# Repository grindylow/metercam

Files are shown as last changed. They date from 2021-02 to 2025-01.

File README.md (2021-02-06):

# MeterCam

A WiFi "webcam" to monitor gas/water/electricity meters, or anything else that
needs regular (daily/weekly/monthly) inspection. When set to weekly intervals,
MeterCam will run on one set of AAA batteries for many years.

## Introduction

The MeterCam combines a standard ESP32-CAM module [1] (which works great, but
consumes a lot of power, even when sleeping) with custom hardware that only
powers up the camera module when it wants to take a picture, for example once
a day/week.

This custom hardware utilises a very energy-efficient "high-side power switch"
and a low-power microcontroller - keeping the power consumption during sleep
periods below 1 µW and resulting in battery lifetimes of many years.

## Features

- [ ] Configurable WiFi SSID/password
- [ ] Extended configuration options
- [ ] Configuration change via MQTT
- [ ] Image output via MQTT
- [ ] image acquisition on boot
- [ ] enable/disable "flash" LED
- [ ] Streaming video over HTTP (for setup)
- [ ] request shutdown

## Setup Instructions

The configuration web interface is based around XYZ's WifiManager[...].

A virgin MeterCam will enter configuration mode when first powered up.

Connect to the MeterCam WiFi Access Point (SSID "METERCAM", password:
"metercam") and configure all parameters as desired.

From now on, MeterCam will wake up at the configured intervals (see
[below](#operation)).

@todo you can force a configured MeterCam to go back into configuration mode
by setting jumper JPx. MeterCam will also fall back to configuration mode if
it hasn't been able to connect to the configured WiFi network five times in a
row (this is a feature of WifiManager).

## Operation

No maintenance is required during regular operation. MeterCam will

 1. wake up every interval
 2. connect to the configured WiFi
 3. take a picture
 4. transmit this picture via the configured means (MQTT, E-Mail, FTP, etc.)
 5. go back to sleep

@todo If MQTT is enabled, the MeterCam will subscribe to the configured "inbox" topic
and interpret incoming configuration requests.

## Detailed Description of MeterCam Components

### MeterCam Printed Circuit Board (PCB)

The MeterCam PCB contains a Microchip PIC16 microcontroller. It communicates
with the ESP32-CAM module via a bidirectional serial link. This link allows the
ESP32-CAM to request power-off and specific sleep durations.

The microcontroller also controls a "high-side power switch" used to cut power
to the ESP32-CAM module - thereby preventing the ESP32-CAM from consuming any
power during periods of inactivity.

### MeterCam µC Firmware

The software running on the MeterCam's microcontroller performs the following
tasks:

 - [ ] On initial bootup, switch *on* ESP32-CAM module, then wait for shutdown
   command .
 - [ ] Switch *off* ESP32-CAM module after 20 seconds, even if no
   (shutdown) command was received. Use a default sleep time of approximately 1 day in this case, if now other time has previously been configured.
 - [ ] Switch *off* ESP32-CAM when requested (via serial connection), and sleep
   for requested duration, consuming as little power as possible.
 - [ ] Switch *on* ESP32-CAM when requested sleep duration has passed.

ESP32-Firmware and µC-Firmware communicate via serial ports. The µC acts as the
slave and will respond to the following commands when transmitted by the ESP32:

| Command | Reply | Explanation |
|---|---|---|
| 'E' | 'e' | Echo request/reply - for testing the connection |
| 'A' <HI> <LO> | 'a' <HI> <LO> | Set new sleep time in 'intervals'. |
| 'S' | 's' | Switch off power to ESP32 'now' and sleep for configured sleep duration |

### MeterCam ESP32-CAM Firmware

Compile using Arduino Studio with ESP extensions and the following libraries:
 - ESP32-CAM
 - [WifiManager](https://github.com/tzapu/WiFiManager)
 - -[DoubleResetDetect](https://github.com/jenscski/DoubleResetDetect)-
 - [EspMQTTClient](https://github.com/plapointe6/EspMQTTClient), which requires...
   - [MQTT PubSubClient](https://github.com/knolleary/pubsubclient)
 - [ArduinoJSON](https://arduinojson.org/)

[1] ESP32-CAM module: ...

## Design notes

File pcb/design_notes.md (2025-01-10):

# Power Supply

The ESP32CAM-Module is designed to operate from 5 V DC power.

According to the schematic, e.g. in [1], this is internally converted to
3.3 V with an AMS1117 regulator. At the expense of additional heat
dissipation, this will easily work with > 5 V.

In an alternative design, we could switch 4.5 V (from 3 AAA batteries) and
convert these to 3.3 V ourselves with a very low drop regulator.

We choose a power supply of 4 x AAA batteries. These will give a voltage of
1.6 V x 4 = 6.4 V (see, e.g., [2]).

The ESP32COM datasheet gives maximum power consumption of 310 mA  @ 5 V.

The AMS1117 guarantees a maximum dropout voltage of 1.3 V. For 3.3 V output,
we can safely operate down to 3.3 V + 1.3 V = 4.6 V.

4.6 V translates into a single battery voltage of 4.6 V / 4 = 1.15 V.

According to [2], when discharged at 250 mA, the battery voltage will drop to
1.15 V in about 1.5 hours. This roughly marks the end of usable live time.

## MCU Power Supply

The Microchip PIC16F15213 is rated from 1.8 V to 5.5 V. However, the
"absolute maximum ratings" list a permissible operating voltage of up to
6.5 V, which is higher than our maximum battery voltage of 6.4 V.

Hence, no additional voltage dropping diodes are needed.

Serial communication to the ESP32 should also work work both at "full" and
"empty" battery voltage levels (tbc).

## Power Switch Power Supply

The SIP32510 is rated for a maximum operating voltage of 6.0 V.

We operate outside the specification by 0.4 V during off periods, which should
not be a problem.

EN input high voltage must be >= 1.8 V (for V_IN = 5.0 V) which will be the
case even at the end of the battery life time.

An alternative design could employ a simple MOSFET instead of a power switch.

The MCU's charge pump feature may be beneficial in this case?

[1]: https://github.com/SeeedDocument/forum_doc/blob/master/reg/ESP32_CAM_V1.6.pdf

[2]: Duracell AAA: https://docs.rs-online.com/3eb6/A700000006538580.pdf

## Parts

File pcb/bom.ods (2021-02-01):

Bill of Materials
MeterCam
r1
 | Mouser-Nr. | Herst.- Nr. | Hersteller | Kunden-Teilenr | Beschreibung | Stückzahl | Preis (EUR) | Gesamtpreis: (EUR)
ICs
1 | 579-PIC16F15213-I/SN | PIC16F15213-I/SN | Microchip |  | 8-Bit Mikrocontroller - MCU | 3 | 0,356 € | 1,07 €
3 | 78-SIP32510DT-T1-GE3 | SIP32510DT-T1-GE3 | Vishay |  | Leistungsschalter IC - Leistungsverteiler 1.1V to 5.5V Slew Rt 3A Cntrld Load Swtch | 3 | 0,322 € | 0,97 €
Capacitors
4 | 80-C0805C104K4R | C0805C104K4RACTU | KEMET |  | Kondensator aus mehreren Keramikschichten MLCC - SMD/SMT 16V 1uF X7R 0805 10% | 9 | 0,085 € | 0,77 €
6 | 80-C0805C103K4R | C0805C103K4RACTU | KEMET |  | Kondensator aus mehreren Keramikschichten MLCC - SMD/SMT 16V 0.01uF X7R 0805 10% | 3 | 0,119 € | 0,36 €
LEDs
7 | 604-AP2012ID | AP2012ID | Kingbright |  | Standard-LEDs - SMD Red 625nm 5mcd 120 Deg | 6 | 0,195 € | 1,17 €
Resistors
8 | 71-CRCW080510K0FKEAC | CRCW080510K0FKEAC | Vishay |  | Dickfilmwiderstände - SMD 1/8Watt 10Kohms 1% Commercial Use | 10 | 0,05 € | 0,50 €
9 | 71-CRCW080520K0FKEAC | CRCW080520K0FKEAC | Vishay |  | Dickfilmwiderstände - SMD 1/8Watt 20Kohms 1% Commercial Use | 6 | 0,085 € | 0,51 €
10 | 71-CRCW0805470RFKEAC | CRCW0805470RFKEAC | Vishay |  | Dickfilmwiderstände - SMD 1/8Watt 470ohms 1% Commercial Use | 3 | 0,085 € | 0,26 €
11 | 71-CRCW08051K00FKEAC | CRCW08051K00FKEAC | Vishay |  | Dickfilmwiderstände - SMD 1/8Watt 1Kohms 1% Commercial Use | 6 | 0,085 € | 0,51 €
12 | 71-CRCW0805100RFKEAC | CRCW0805100RFKEAC | Vishay |  | Dickfilmwiderstände - SMD 1/8Watt 100ohms 1% Commercial Use | 3 | 0,085 € | 0,26 €
Connectors
13 | 200-SNT100BKT | SNT-100-BK-T | Samtec |  | Sockel & Kabelgehäuse .100" Shunt | 9 | 0,169 € | 1,52 €
14 | 538-22-28-4360 | 22-28-4360 | Molex |  | Sockel & Kabelgehäuse 36P 1 ROW VERT HDR | 2 | 0,686 € | 1,37 €
2 | 200-SSW10801TS | SSW-108-01-T-S | Samtec |  | Platine-zu-Platine & Mezzanine-Steckverbinder .100" Tiger Buy Socket Strip | 6 | 0,695 € | 4,17 €
Other
5 | 12BH431/C-GR | 12BH431/C-GR | Eagle Plastic Devices |  | Batteriegehäuse 3 AAA W/COVER | 3 | 1,81 € | 5,43 €
15 | 5174-11161 | FP301-1/16-48"-Black-Bulk | 3M |  | Wärmeschrumpfschläuche & -hülsen 2:1 Thin Wall 1/16, 48" Black | 1 | 1,49 € | 1,49 €

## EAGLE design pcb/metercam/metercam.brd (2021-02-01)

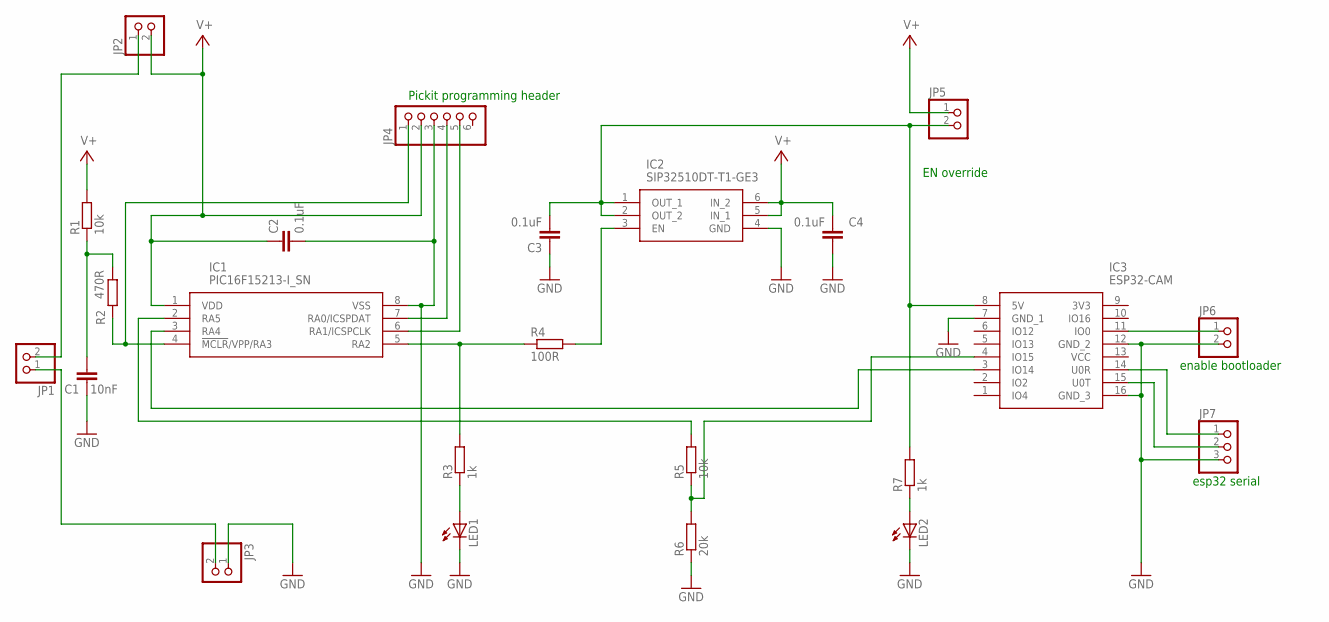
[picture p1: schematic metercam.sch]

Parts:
C1: 10nF; C0805
C2, C3, C4: 0.1uF; C0805
IC1: PIC16F15213-I_SN; SOIC127P600X175-8N
IC2: SIP32510DT-T1-GE3; SOT95P284X110-6N
IC3: ESP32-CAM; ESP32CAM
JP1, JP2, JP3, JP5, JP6: PINHD-1X2; 1X02
JP4: PINHD-1X6; 1X06
JP7: PINHD-1X3; 1X03
LED1, LED2: LEDSML0805; SML0805
R1, R5: 10k; R0805
R2: 470R; R0805
R3, R7: 1k; R0805
R4: 100R; R0805
R6: 20k; R0805

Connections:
GND: C1.1, C2.2, C3.1, C4.1, IC1.8 (VSS), IC2.4 (GND), IC3.7 (GND_1), IC3.12 (GND_2), IC3.16 (GND_3), JP3.1, JP4.3, JP6.2, JP7.3, LED1.C, LED2.C, R6.1
unnamed: IC1.4 (!MCLR!/VPP/RA3), JP4.1, R2.1
unnamed: IC3.14 (U0R), JP7.1
unnamed: JP1.2, JP2.1
unnamed: IC1.7 (RA0/ICSPDAT), JP4.4
unnamed: IC1.6 (RA1/ICSPCLK), JP4.5
unnamed: IC3.11 (IO0), JP6.1
unnamed: JP1.1, JP3.2
unnamed: IC3.15 (U0T), JP7.2
unnamed: IC1.5 (RA2), R3.2, R4.1
unnamed: IC2.3 (EN), R4.2
unnamed: C3.2, IC2.1 (OUT_1), IC2.2 (OUT_2), IC3.8 (5V), JP5.2, R7.2
unnamed: LED2.A, R7.1
unnamed: LED1.A, R3.1
unnamed: IC1.3 (RA4), IC3.3 (IO14)
unnamed: IC1.2 (RA5), R5.2
unnamed: IC3.4 (IO15), R5.1, R6.2
unnamed: C1.2, R1.1, R2.2
V+: C2.1, C4.2, IC1.1 (VDD), IC2.5 (IN_1), IC2.6 (IN_2), JP2.2, JP4.2, JP5.1, R1.2

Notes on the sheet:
Pickit programming header
enable bootloader
esp32 serial
EN override

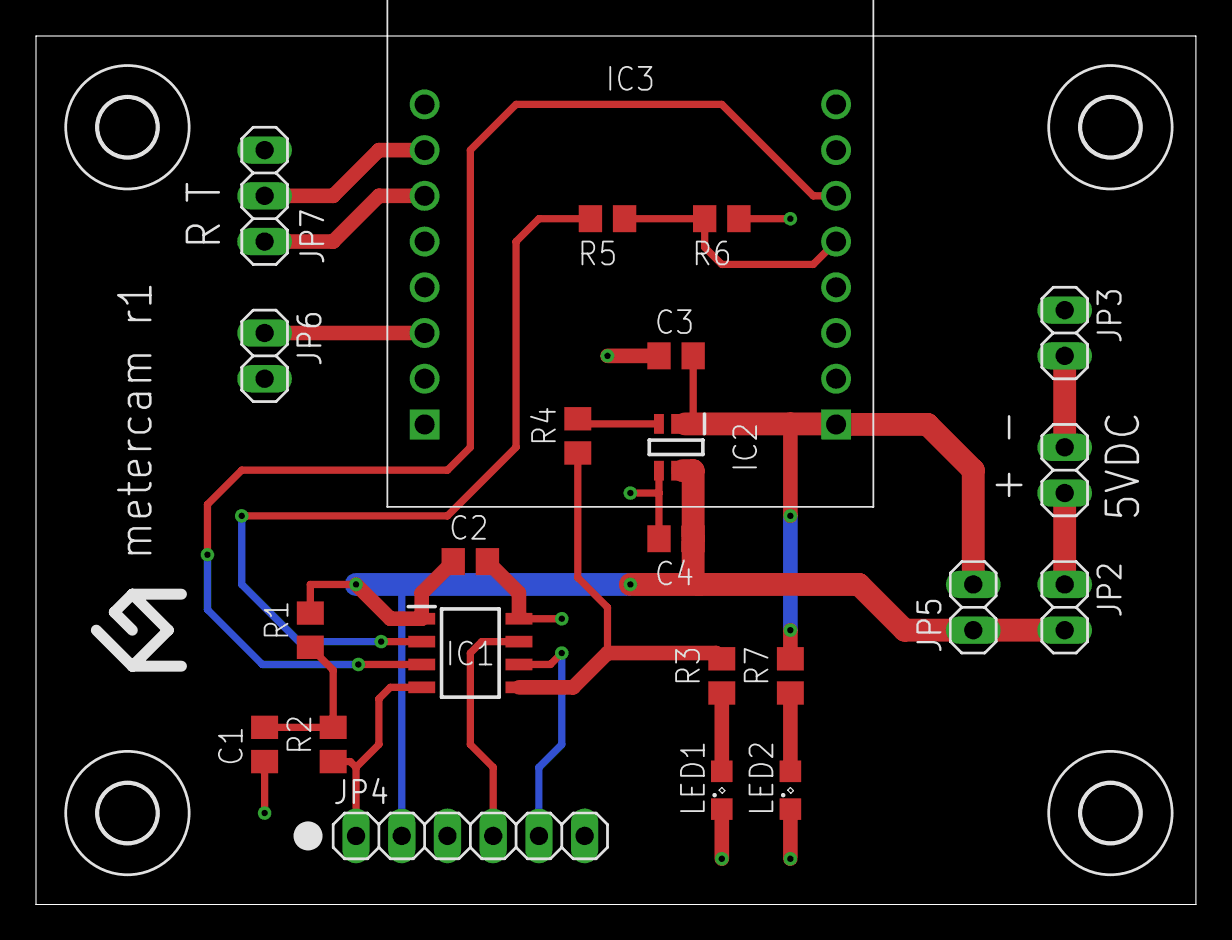
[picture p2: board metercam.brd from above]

Board: 2 copper layers, 64.4 x 48.2 mm, 27 parts (0 on the bottom side), 19 nets.

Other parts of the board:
U$1, U$2, U$3, U$4: 3,2

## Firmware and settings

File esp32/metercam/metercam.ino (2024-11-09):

/* MeterCam by Martin Grill
 *  ......
 * License: ...
 */

/* https://github.com/khoih-prog/ESP_DoubleResetDetector/  -  EEPROM doesn't work, LITTLEFS crashes! */
//#include <ESP_DoubleResetDetector.h>  

/* https://github.com/tzapu/WiFiManager */
#include <WiFiManager.h>  

///* https://github.com/plapointe6/EspMQTTClient */
//#include "EspMQTTClient.h"


#include <ArduinoJson.h>

#include <PubSubClient.h>

#include <ESPAsyncWebServer.h>

/* we use LittleFS for storing settings */
#include <LittleFS.h>

/* This project does not share any code with Rui Santos's esp32-cam project. Nevertheless,
 * Rui's contribution to the esp32-cam universe is hereby gratefully acknowledged.
 * Complete project details at https://RandomNerdTutorials.com/esp32-cam-take-photo-display-web-server/
 */

// our own submodules
#include "mywebserver.h"
#include "camoperator.h"

WiFiManager myWiFiManager;
AsyncWebServer server(80);
CamOperator myCamOperator;

const char *mqtt_server = "192.168.88.203";
WiFiClient espClient;
PubSubClient myPubSubClient(espClient);

/** After taking a picture, we stay awake a little in case someone wants
  * to talk to us over MQTT. */
unsigned long whenShouldIGoToSleep = ULONG_MAX;

/** We will tell the uC to sleep this many intervals - can be reconfigured
  * by sending us an MQTT message. */
uint16_t desired_sleep_intervals = 0;  // Special value 0: "do not set new value before going to sleep"

/** a new MQTT message arrived */
void callback(char* topic, byte* payload, unsigned int length) {
  Serial.print("Message arrived [");
  Serial.print(topic);
  Serial.print("] ");
  for (int i = 0; i < length; i++) {
    Serial.print((char)payload[i]);
  }
  Serial.println();

  // Deserialize the JSON document
  StaticJsonDocument<200> doc;
  DeserializationError error = deserializeJson(doc, payload, length);
  if (error) {
    Serial.print(F("deserializeJson() failed: "));
    Serial.println(error.f_str());
    return;
  }
  desired_sleep_intervals = doc["sleep_intervals"];
  Serial.printf("desired_sleep_intervals = %u\n", desired_sleep_intervals);
}

void onConnectionEstablished() {
/*
  myMQTTClient.subscribe("mytopic/test", [] (const String &payload)  {
    Serial.println(payload);
  });

  myMQTTClient.publish("mytopic/test", "This is a message");
  */
}

void onNewPicture(int _size, const uint8_t* _buf)
{
  Serial.printf("onNewPicture(size=%d,buf=%d)\n", _size, _buf);
  if(_size>UINT16_MAX)
  {
    Serial.println("- too large for our MQTT implementation :-(. not transmitting.");
    return;
  }
  boolean r;
  r = myPubSubClient.publish("metercam/DEADBEEF/jpg", _buf, _size);
  Serial.printf("publish result: %d\n", (int)r);
  whenShouldIGoToSleep = millis() + 2000;
  //myMQTTClient.publish("mytopic/img", std::string(_buf, _buf+_size));
}

void setup() {
  boolean r;
  Serial.begin(115200);  // "Serial" is for debugging output
  Serial.println("entered setup()");

  Serial.println("** Normal boot **");
  myWiFiManager.autoConnect("METERCAM", "metercam");

  // start web server
  init_webserver(server, &myCamOperator);
  server.begin();

  // Configure MQTT connection
  myPubSubClient.setServer(mqtt_server, 1883);
  myPubSubClient.setCallback(callback);
  r = myPubSubClient.setBufferSize(60000);
  Serial.printf("myPubSubClient.setBufferSize() = %d\n", (int)r);
    
  // initialise camera
  myCamOperator.registerNewPictureCallback(onNewPicture);
  myCamOperator.init();

  // whenever we boot, we take a picture right away
  myCamOperator.requestPicture();

  // comms to/from µC
#define RXD2 15 // 16
#define TXD2 14 // 17
  Serial2.begin(9600, SERIAL_8N1, RXD2, TXD2);

  whenShouldIGoToSleep = 0;
  Serial.println("setup() finished");
}

void reconnectPubSubClient() {
  // Loop until we're reconnected
  while (!myPubSubClient.connected()) {
    Serial.print("Attempting MQTT connection...");
    // Create a random client ID
    String clientId = "ESP8266Client-";
    clientId += String(random(0xffff), HEX);
    // Attempt to connect
    if (myPubSubClient.connect(clientId.c_str())) {
      Serial.println("connected");
      // Once connected, subscribe to inbox...
      myPubSubClient.subscribe("metercam/DEADBEEF/inbox");
      // ...and announce ourselves.
      myPubSubClient.publish("metercam/DEADBEEF/info", "about to take a picture");
    } else {
      Serial.print("failed, rc=");
      Serial.print(myPubSubClient.state());
      Serial.println(" try again in 5 seconds");
      // Wait 5 seconds before retrying
      delay(5000);
    }
  }
}


void loop() {
  unsigned long myTime;
  if(Serial2.available()) {
    Serial.print("Got something: ");
    char c=Serial2.read();
    Serial.printf("0x%02x\n", c);
  }
  //delay(1000);
  reconnectPubSubClient();  // will only reconnect if not alread connected
  myPubSubClient.loop();
  myCamOperator.loop();
  if(millis()>whenShouldIGoToSleep)
  {
    if(desired_sleep_intervals)
    {
      Serial.printf("About to set new number of desired sleep intervals to %u...\n", desired_sleep_intervals);
      Serial2.write('A');
      Serial2.write((uint8_t)((desired_sleep_intervals>>8)&0xff));
      Serial2.write((uint8_t)(desired_sleep_intervals&0xff));
      desired_sleep_intervals = 0;
      whenShouldIGoToSleep += 500;  // give us a chance to also see the reply
    }
    else
    {
      Serial.print("About to go to sleep.\n");
      Serial2.print("S"); // "go to sleep now!"
      delay(1000);
      Serial.print("If you can see this, the 'S' command wasn't processed for some reason.\n");
    }
  }
}

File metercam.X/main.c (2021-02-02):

/**
  Generated Main Source File

  Company:
    Microchip Technology Inc.

  File Name:
    main.c

  Summary:
    This is the main file generated using PIC10 / PIC12 / PIC16 / PIC18 MCUs

  Description:
    This header file provides implementations for driver APIs for all modules selected in the GUI.
    Generation Information :
        Product Revision  :  PIC10 / PIC12 / PIC16 / PIC18 MCUs - 1.81.6
        Device            :  PIC16F15213
        Driver Version    :  2.00
*/

/*
    (c) 2018 Microchip Technology Inc. and its subsidiaries. 
    
    Subject to your compliance with these terms, you may use Microchip software and any 
    derivatives exclusively with Microchip products. It is your responsibility to comply with third party 
    license terms applicable to your use of third party software (including open source software) that 
    may accompany Microchip software.
    
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
    IN NO EVENT WILL MICROCHIP BE LIABLE FOR ANY INDIRECT, SPECIAL, PUNITIVE, 
    INCIDENTAL OR CONSEQUENTIAL LOSS, DAMAGE, COST OR EXPENSE OF ANY KIND 
    WHATSOEVER RELATED TO THE SOFTWARE, HOWEVER CAUSED, EVEN IF MICROCHIP 
    HAS BEEN ADVISED OF THE POSSIBILITY OR THE DAMAGES ARE FORESEEABLE. TO 
    THE FULLEST EXTENT ALLOWED BY LAW, MICROCHIP'S TOTAL LIABILITY ON ALL 
    CLAIMS IN ANY WAY RELATED TO THIS SOFTWARE WILL NOT EXCEED THE AMOUNT 
    OF FEES, IF ANY, THAT YOU HAVE PAID DIRECTLY TO MICROCHIP FOR THIS 
    SOFTWARE.
*/

#include "mcc_generated_files/mcc.h"
#include "metercam.h"
/*
                         Main application
 */
void main(void)
{
    SYSTEM_Initialize();

    INTERRUPT_GlobalInterruptEnable();
    INTERRUPT_PeripheralInterruptEnable();

    app_metercam();
    // will never return
}
/**
 End of File
*/
